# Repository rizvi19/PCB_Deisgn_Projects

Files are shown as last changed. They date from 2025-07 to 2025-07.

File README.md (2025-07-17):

# USB-C to UART Converter PCB

This repository contains the design files, schematics, and documentation for a custom USB-C to UART converter Printed Circuit Board (PCB). The project aims to provide a compact, reliable, and user-friendly solution for serial communication between a modern computer with a USB-C port and a microcontroller or other serial device operating at UART logic levels. The design leverages the **CP2102** USB-to-UART bridge IC, a USB-C connector, and ESD protection for robust performance.

## Features
- **USB-C Connectivity:** Modern, reversible USB-C connector supporting USB 2.0 Full Speed (12 Mbps).
- **CP2102 USB-to-UART Bridge:** Reliable single-chip solution for converting USB data to TTL-level UART signals.
- **ESD Protection:** LESD5D5.0CT1G diode array protects USB data lines from ±15 kV electrostatic discharge events.
- **Visual Feedback:** LEDs indicate power status and TX/RX data activity.
- **Compact Design:** Small form factor suitable for embedded systems development and prototyping.
- **Pin Header:** Provides easy access to UART signals (TX, RX, GND) and 3.3V power output.
- **Wide Baud Rate Support:** Configurable baud rates (e.g., 9600, 115200 bps) for compatibility with various microcontrollers.
- **Open-Source:** All design files (schematics, PCB layout, BOM) are available in this repository.

## Repository Contents
- `/schematics`: KiCad schematic files for the USB-C to UART converter.
- `/pcb`: KiCad PCB layout files and Gerber files for manufacturing.
- `/3d_models`: 3D visualization files of the assembled PCB.
- `/docs`: Project documentation, including the detailed design report (`USB-C_to_UART_Converter_Report.pdf`).
- `/bom`: Bill of Materials (BOM) listing all components with part numbers and suppliers.

## Hardware Overview
The PCB integrates the following key components:
- **CP2102:** Converts USB data to UART signals, enumerates as a Virtual COM Port (VCP) on the host computer.
- **USB-C Receptacle:** Provides a modern interface with VBUS (5V), GND, and USB 2.0 data lines (D+, D-).
- **LESD5D5.0CT1G:** ESD protection for USB data lines to enhance durability.
- **LEDs and Resistors:** Power LED (3.3V) and activity LED (TX/RX) with current-limiting resistors (330 Ω).
- **Capacitors:** Decoupling capacitors (0.1 µF, 1 µF, 4.7 µF) for power stability.
- **Pin Header:** 4-pin header for TX, RX, GND, and 3.3V output.

## User Manual
### Prerequisites
- A computer with a USB-C port and drivers for the CP2102 (available from [Silicon Labs](https://www.silabs.com/interface/usb-bridges/classic/device.cp2102)).
- A microcontroller or serial device with UART interface (3.3V or 5V logic levels).
- Jumper wires or a compatible connector for the pin header.
- Terminal software (e.g., PuTTY, Tera Term, or Arduino Serial Monitor) for serial communication.

### Setup Instructions
1. **Driver Installation:**
   - Download and install the CP2102 VCP drivers from [Silicon Labs](https://www.silabs.com/interface/usb-bridges/classic/device.cp2102).
   - Upon connecting the PCB to your computer via a USB-C cable, it should enumerate as a COM port (e.g., COM3 on Windows or `/dev/ttyUSB0` on Linux).

2. **Connecting to a Microcontroller:**
   - Connect the PCB’s pin header to your microcontroller:
     - **TX (PCB)** → **RX (Microcontroller)**
     - **RX (PCB)** → **TX (Microcontroller)**
     - **GND (PCB)** → **GND (Microcontroller)**
     - (Optional) **3.3V (PCB)** → Power input for the microcontroller (if needed, ensure current draw < 100 mA).
   - Use jumper wires or a compatible connector for secure connections.

3. **Configuring the Serial Port:**
   - Open your terminal software and select the appropriate COM port.
   - Set the baud rate to match your microcontroller (e.g., 9600, 115200 bps).
   - Configure other settings (typically 8 data bits, no parity, 1 stop bit, no flow control).

4. **Testing Communication:**
   - Power on the microcontroller and send data (e.g., via a simple `Serial.print()` in Arduino).
   - The activity LED on the PCB should blink during data transfer.
   - Verify that data appears in the terminal software and vice versa.

### LED Indicators
- **Power LED:** Lights up when the PCB is powered via USB (indicates 3.3V regulator is active).
- **Activity LED:** Blinks during TX or RX data transfers, providing visual feedback of serial communication.

### Troubleshooting
- **No COM Port Detected:** Ensure the CP2102 drivers are installed and the USB-C cable is functional (try a different cable/port).
- **No Data Transfer:** Verify TX/RX connections are correct (not swapped) and the baud rate matches on both devices.
- **LED Not Lighting:** Check USB power and connections; ensure the LED resistors are properly soldered.
- **Unstable Operation:** Inspect solder joints and verify that decoupling capacitors are correctly placed.

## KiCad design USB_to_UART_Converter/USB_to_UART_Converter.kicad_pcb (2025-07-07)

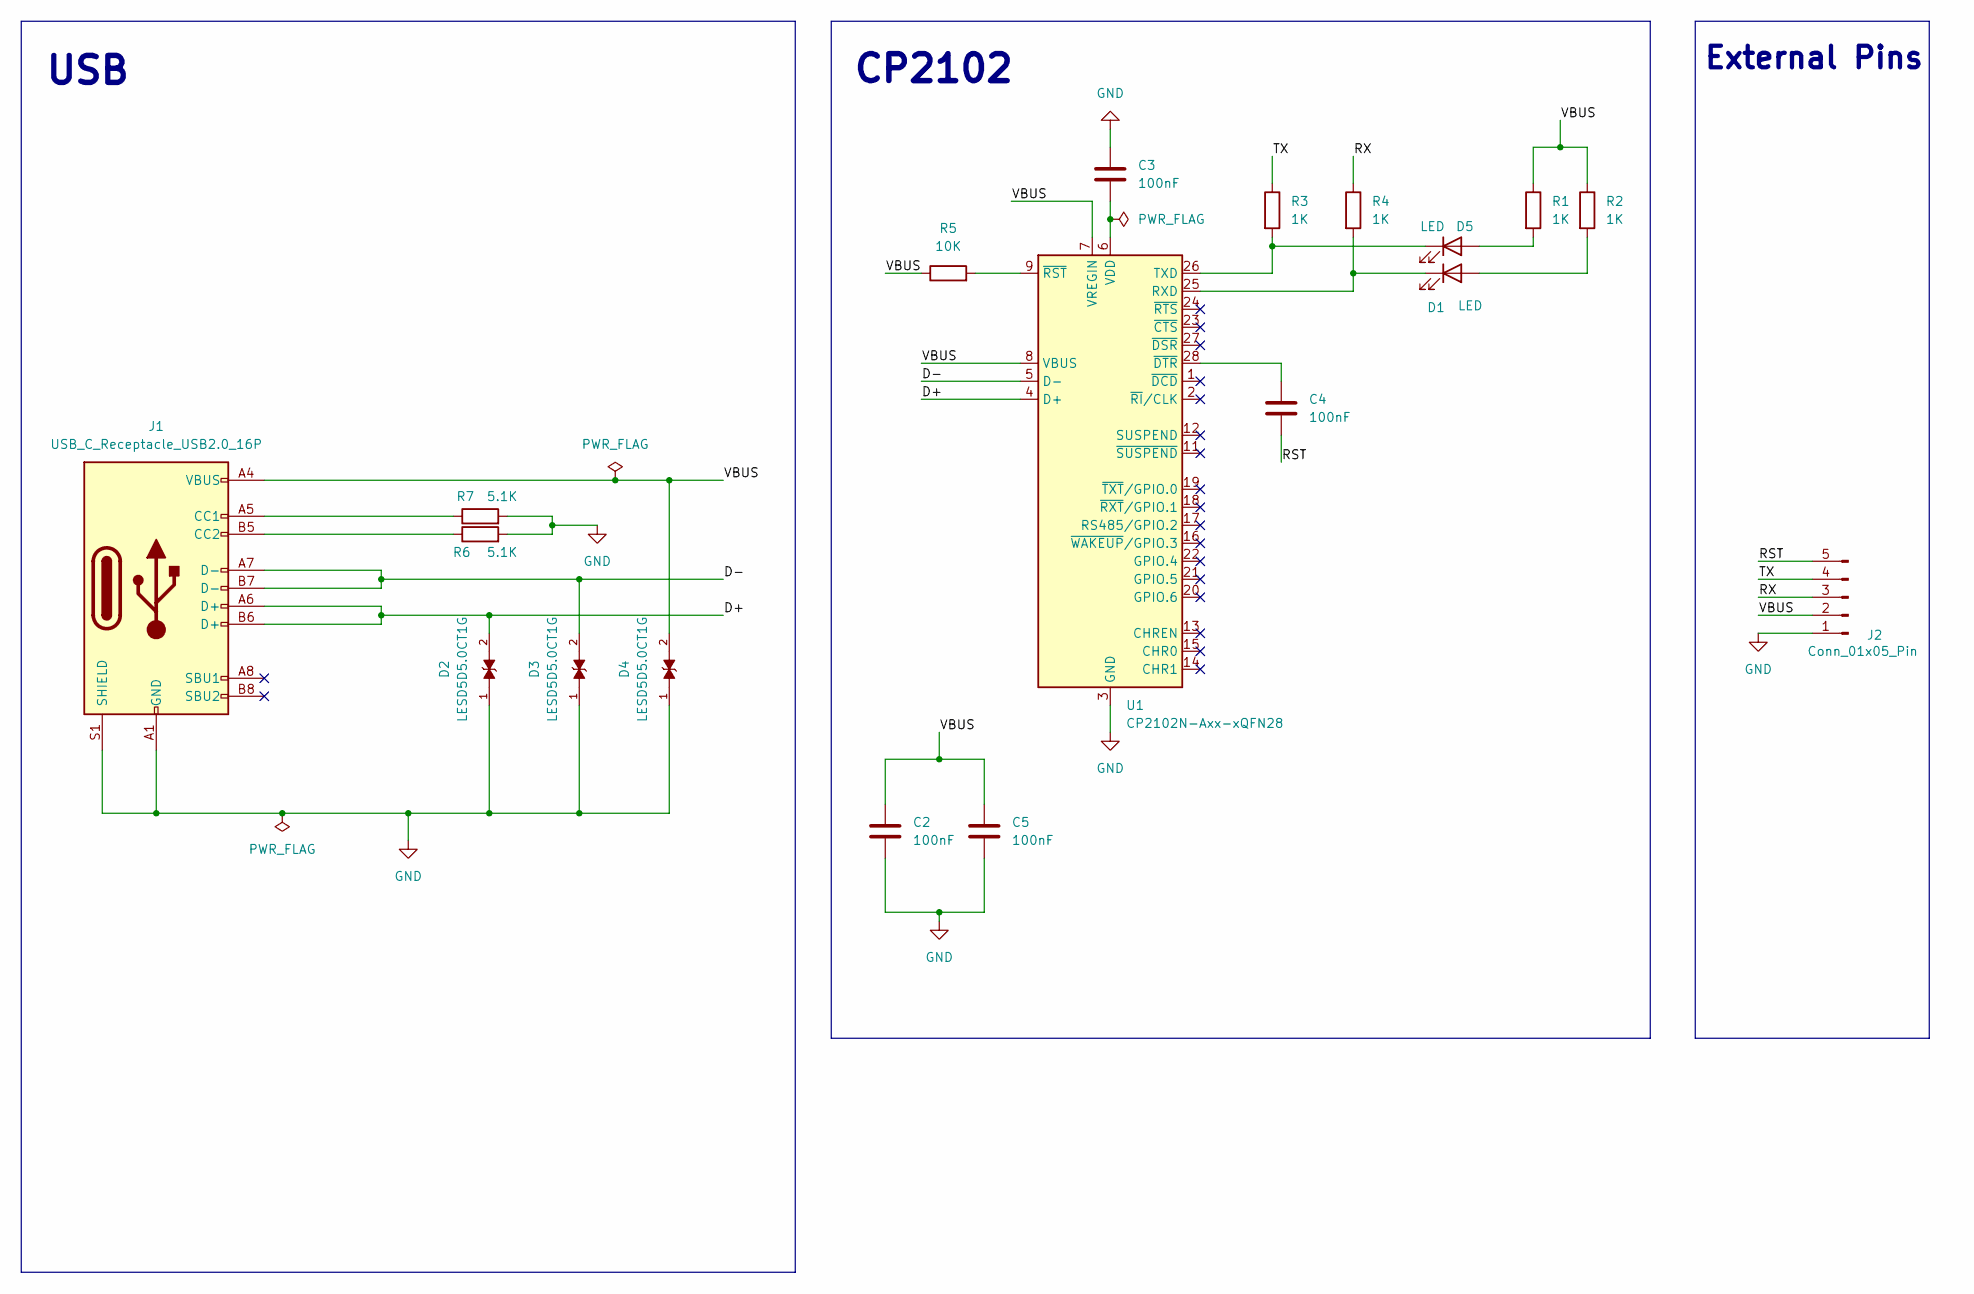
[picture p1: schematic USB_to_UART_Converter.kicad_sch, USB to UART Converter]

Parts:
C2, C3, C4, C5: 100nF; C_0201_0603Metric
D1, D5: LED; LED_0201_0603Metric
D2, D3, D4: LESD5D5.0CT1G; TVS_LESD5D5.0CT1G; PARTREV O
J1: USB_C_Receptacle_USB2.0_16P; USB_C_Receptacle_HRO_TYPE-C-31-M-12
J2: Conn_01x05_Pin; PinHeader_1x05_P2.54mm_Horizontal
R1, R2, R3, R4: 1K; R_0201_0603Metric
R5: 10K; R_0201_0603Metric
R6, R7: 5.1K; R_0201_0603Metric
U1: CP2102N-Axx-xQFN28; QFN-28-1EP_5x5mm_P0.5mm_EP3.35x3.35mm

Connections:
/D+: D2.2, J1.A6 (D+), J1.B6 (D+), U1.4 (D+)
/D-: D3.2, J1.A7 (D-), J1.B7 (D-), U1.5 (D-)
/RST: C4.2, J2.5
/RX: J2.3, R4.1
/TX: J2.4, R3.1
/VBUS: C2.1, C5.1, D4.2, J1.A4 (VBUS), J1.A9 (VBUS), J1.B4 (VBUS), J1.B9 (VBUS), J2.2, R1.1, R2.1, R5.1, U1.7 (VREGIN), U1.8 (VBUS)
GND: C2.2, C3.1, C5.2, D2.1, D3.1, D4.1, J1.A1 (GND), J1.A12 (GND), J1.B1 (GND), J1.B12 (GND), J1.S1 (SHIELD), J2.1, R6.2, R7.2, U1.3 (GND), U1.29 (GND)
unnamed: D1.2 (A), R2.2
unnamed: D1.1 (K), R4.2, U1.25 (RXD)
unnamed: D5.2 (A), R1.2
unnamed: D5.1 (K), R3.2, U1.26 (TXD)
unnamed: J1.A5 (CC1), R7.1
unnamed: J1.B5 (CC2), R6.1
unnamed: C3.2, U1.6 (VDD)
unnamed: C4.1, U1.28 (~DTR)
unnamed: R5.2, U1.9 (~RST)

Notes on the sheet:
USB
External Pins
CP2102

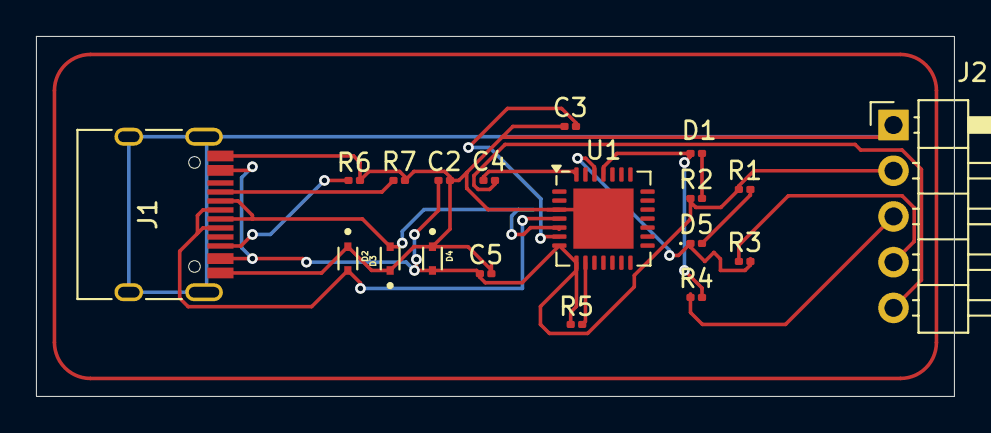
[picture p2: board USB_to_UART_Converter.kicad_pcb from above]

Board: 2 copper layers, 51.0 x 20.0 mm, 19 parts (0 on the bottom side), 16 nets.
